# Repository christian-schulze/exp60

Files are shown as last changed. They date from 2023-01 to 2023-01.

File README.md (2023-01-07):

# Exp60 - An opinionated 60% with arrow keys PCB

---

> **Warning** WIP - Functioning prototype not built yet.
>
> - Components ordered (2023-01-06).
> - PCB's ordered (2023-01-07).

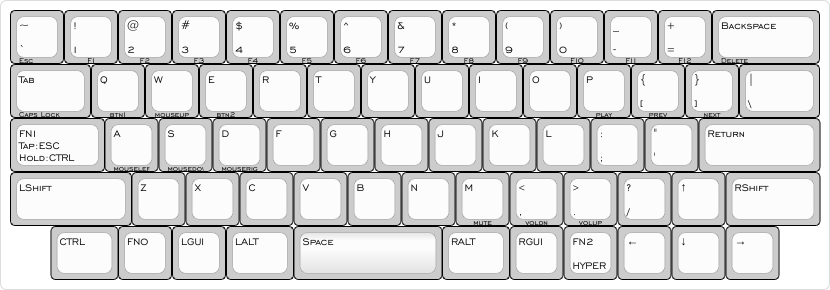
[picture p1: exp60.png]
Exp60 Layout


[Link to Keyboard Layout Editor project](http://www.keyboard-layout-editor.com/#/gists/84f70adc6e3be321baacc794c3d78efd)

## Why?

I've always preferred the size of a 60%, but never managed to kick the arrow key addiction. Having tried the `dz60` and `dz64` from kbdfans (dz64 being my fav), they both have trade-offs I've never been quite happy with.

## Design constraints

1. 60% form factor, roughly the same size as a GH60.
2. Arrow cluster
3. Standard 2.25U left shift
4. Standard 1U forward slash / question mark key
5. Bottom row should have `CTRL`, `Fn`, `GUI`, `ALT` and `HYPER` keys
6. USB-C
7. Hot-swap
8. Hand solderable

## How was this layout chosen?

In order to meet design constraints 2, 3 and 4, the arrow cluster needs to be located next to the forward slash key. The right arrow key only has 0.75U of space to its right, so we have the `HHKB-esque` gaps at the edges of the bottom row.

To meet design constraint 5, the space bar needs to be shrunk to 2.75U. I've been daily driving a heavily modded `HHKB Pro JP` since 2017 so this is A-OK to me.

## PCB Design choices

1. All SMD components due to limited space.
2. Use `atmega32u2-au` MCU instead of `atmega32u4-au` due to limited space (32 vs 48 pins).
3. Large footprint SMD components so everything is more easily hand solderable.

## Acknowledgements

- [JP60 by ai03](https://github.com/ai03-2725/JP60)

  60%, USB-C, ESD and over voltage/currrent protection.

- [Keyboard Matías](https://github.com/nstrappazzonc/keyboard)

  This uses the `atmega32u2-au`, which is crucial for fitting the MCU and related traces on my PCB.

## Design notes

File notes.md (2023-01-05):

switch gap:
5.050

switch width:
14

stab width:
7.250

------------------------------------------------

switch radius:
9.525

x1: 80.455 - 9.525 = 70.930
y1: 93.155 - 9.525 = 83.630

x2: 340.01125 + 16.669 = 356.68025
y2: 169.355 + 9.525 = 178.880

w: 356.68025 - 70.930 = 285.75025
h: 178.880 - 83.630 = 95.25

diode position from center of switch:
x: 7.65125
y: 1.500

parallel diode gap:
2.95

parallel horizontal diode:
x: 5.04875
y: 3.145
gap: 2.95

column via gaps:
X: 78.1325 - 76.2 = 1.9325
Y: 99.21875 - 98.235 = 0.98375

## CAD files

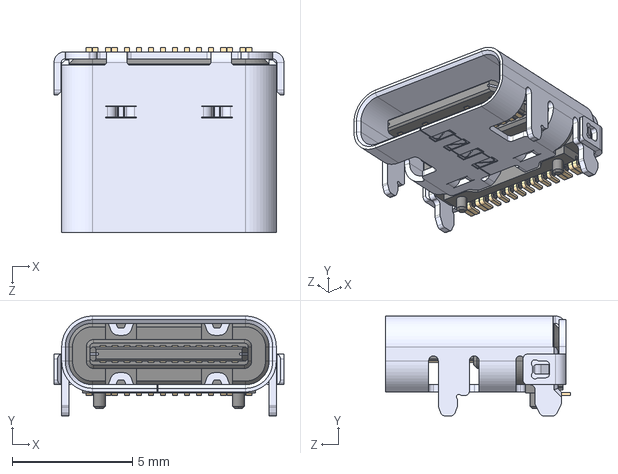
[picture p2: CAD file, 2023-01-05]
kicad/USB4105-GF-A/USB4105-GF-A.step
9.58 x 4.16 x 7.71 mm

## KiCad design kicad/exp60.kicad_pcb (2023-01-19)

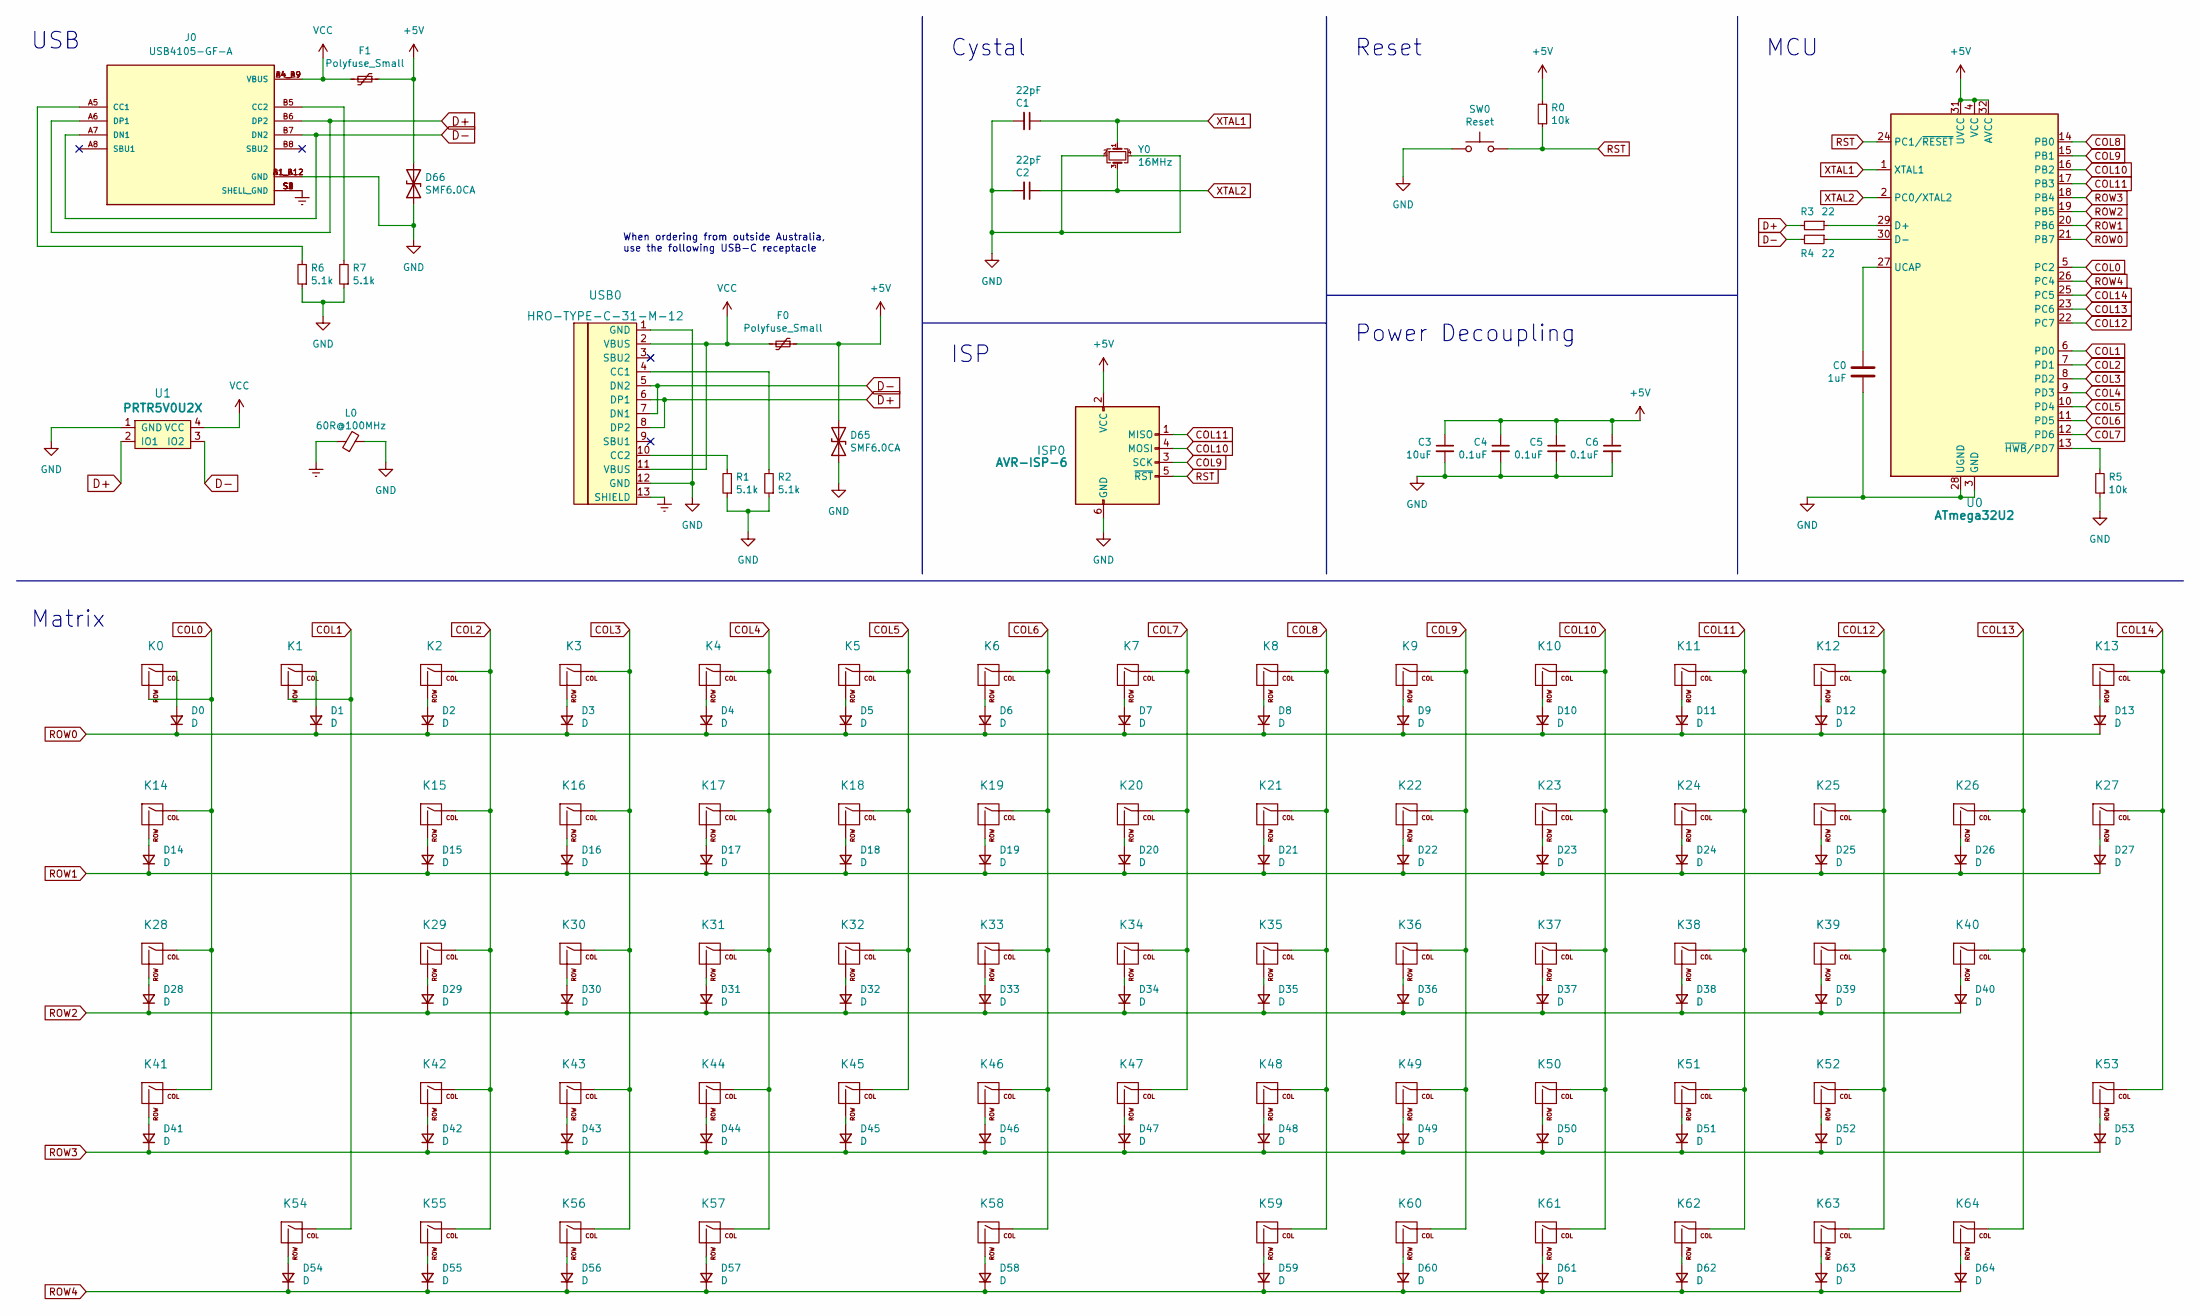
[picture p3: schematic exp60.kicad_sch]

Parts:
C0: 1uF; C_0805_2012Metric
C1, C2: 22pF; C_0805_2012Metric
C3: 10uF; C_0805_2012Metric
C4, C5, C6: 0.1uF; C_0805_2012Metric
D0, D1, D2, D3, D4, D5, D6, D7, D8, D9, D10, D11, D12, D13, D14, D15, D16, D17, D18, D19, D20, D21, D22, D23, D24, D25, D26, D27, D28, D29, D30, D31, D32, D33, D34, D35, D36, D37, D38, D39, D40, D41, D42, D43, D44, D45, D46, D47, D48, D49, D50, D51, D52, D53, D54, D55, D56, D57, D58, D59, D60, D61, D62, D63, D64: D; D_SOD-123
D65, D66: SMF6.0CA; D_SOD-123
F0, F1: Polyfuse_Small; Fuse_1206_3216Metric
ISP0: AVR-ISP-6; CON_TC2030_outlined
J0: USB4105-GF-A; GCT_USB4105-GF-A-HandSoldering; PARTREV A3
K0, K1, K2, K3, K4, K5, K6, K7, K8, K9, K10, K11, K12, K15, K16, K17, K18, K19, K20, K21, K22, K23, K24, K25, K26, K29, K30, K31, K32, K33, K34, K35, K36, K37, K38, K39, K42, K43, K44, K45, K46, K47, K48, K49, K50, K51, K52, K55, K56, K60, K61, K62, K63, K64: KEYSW; MXOnly-1U-Hotswap
K13: KEYSW; MXOnly-2U-Hotswap
K14, K27: KEYSW; MXOnly-1.5U-Hotswap
K28, K53: KEYSW; MXOnly-1.75U-Hotswap
K40, K41: KEYSW; MXOnly-2.25U-Hotswap
K54, K57, K59: KEYSW; MXOnly-1.25U-Hotswap
K58: KEYSW; MXOnly-2.75U-Hotswap-ReversedStabilizers
L0: 60R@100MHz; L_1206_3216Metric
R0, R5: 10k; R_0805_2012Metric
R1, R2, R6, R7: 5.1k; R_0805_2012Metric
R3, R4: 22; R_0805_2012Metric
SW0: Reset; SW_SPST_SKQG_WithStem
U0: ATmega32U2; TQFP-32_7x7mm_P0.8mm
U1: PRTR5V0U2X; SOT-143_Handsoldering
USB0: HRO-TYPE-C-31-M-12; HRO-TYPE-C-31-M-12-HandSoldering
Y0: 16MHz; Crystal_SMD_3225-4Pin_3.2x2.5mm_HandSoldering

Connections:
+5V: C3.1, C4.1, C5.1, C6.1, D65.2 (A2), D66.2 (A2), F0.1, F1.1, ISP0.2 (VCC), R0.2, U0.4 (VCC), U0.31 (UVCC), U0.32 (AVCC)
COL0: K0.2 (ROW), K14.1 (COL), K28.1 (COL), K41.1 (COL), U0.5 (PC2)
COL1: K1.2 (ROW), K54.1 (COL), U0.6 (PD0)
COL2: K2.1 (COL), K15.1 (COL), K29.1 (COL), K42.1 (COL), K55.1 (COL), U0.7 (PD1)
COL3: K3.1 (COL), K16.1 (COL), K30.1 (COL), K43.1 (COL), K56.1 (COL), U0.8 (PD2)
COL4: K4.1 (COL), K17.1 (COL), K31.1 (COL), K44.1 (COL), K57.1 (COL), U0.9 (PD3)
COL5: K5.1 (COL), K18.1 (COL), K32.1 (COL), K45.1 (COL), U0.10 (PD4)
COL6: K6.1 (COL), K19.1 (COL), K33.1 (COL), K46.1 (COL), K58.1 (COL), U0.11 (PD5)
COL7: K7.1 (COL), K20.1 (COL), K34.1 (COL), K47.1 (COL), U0.12 (PD6)
COL8: K8.1 (COL), K21.1 (COL), K35.1 (COL), K48.1 (COL), K59.1 (COL), U0.14 (PB0)
COL9: ISP0.3 (SCK), K9.1 (COL), K22.1 (COL), K36.1 (COL), K49.1 (COL), K60.1 (COL), U0.15 (PB1)
COL10: ISP0.4 (MOSI), K10.1 (COL), K23.1 (COL), K37.1 (COL), K50.1 (COL), K61.1 (COL), U0.16 (PB2)
COL11: ISP0.1 (MISO), K11.1 (COL), K24.1 (COL), K38.1 (COL), K51.1 (COL), K62.1 (COL), U0.17 (PB3)
COL12: K12.1 (COL), K25.1 (COL), K39.1 (COL), K52.1 (COL), K63.1 (COL), U0.22 (PC7)
COL13: K26.1 (COL), K40.1 (COL), K64.1 (COL), U0.23 (PC6)
COL14: K13.1 (COL), K27.1 (COL), K53.1 (COL), U0.25 (PC5)
D+: J0.A6 (DP1), J0.B6 (DP2), R3.2, U1.2 (IO1), USB0.6 (DP1), USB0.8 (DP2)
D-: J0.A7 (DN1), J0.B7 (DN2), R4.2, U1.3 (IO2), USB0.5 (DN2), USB0.7 (DN1)
Earth: J0.S1 (SHELL_GND), J0.S2 (SHELL_GND), J0.S3 (SHELL_GND), J0.S4 (SHELL_GND), L0.1, USB0.13 (SHIELD)
GND: C0.2, C1.2, C2.2, C3.2, C4.2, C5.2, C6.2, D65.1 (A1), D66.1 (A1), ISP0.6 (GND), J0.A1_B12 (GND), J0.B1_A12 (GND), L0.2, R1.1, R2.1, R5.1, R6.1, R7.1, SW0.2, U0.3 (GND), U0.28 (UGND), U1.1 (GND), USB0.1 (GND), USB0.12 (GND), Y0.2, Y0.4
unnamed: C0.1, U0.27 (UCAP)
unnamed: D0.2 (A), K0.1 (COL)
unnamed: D1.2 (A), K1.1 (COL)
unnamed: D2.2 (A), K2.2 (ROW)
unnamed: D3.2 (A), K3.2 (ROW)
unnamed: D4.2 (A), K4.2 (ROW)
unnamed: D5.2 (A), K5.2 (ROW)
unnamed: D6.2 (A), K6.2 (ROW)
unnamed: D7.2 (A), K7.2 (ROW)
unnamed: D8.2 (A), K8.2 (ROW)
unnamed: D9.2 (A), K9.2 (ROW)
unnamed: D10.2 (A), K10.2 (ROW)
unnamed: D11.2 (A), K11.2 (ROW)
unnamed: D12.2 (A), K12.2 (ROW)
unnamed: D13.2 (A), K13.2 (ROW)
unnamed: D14.2 (A), K14.2 (ROW)
unnamed: D15.2 (A), K15.2 (ROW)
unnamed: D16.2 (A), K16.2 (ROW)
unnamed: D17.2 (A), K17.2 (ROW)
unnamed: D18.2 (A), K18.2 (ROW)
unnamed: D19.2 (A), K19.2 (ROW)
unnamed: D20.2 (A), K20.2 (ROW)
unnamed: D21.2 (A), K21.2 (ROW)
unnamed: D22.2 (A), K22.2 (ROW)
unnamed: D23.2 (A), K23.2 (ROW)
unnamed: D24.2 (A), K24.2 (ROW)
unnamed: D25.2 (A), K25.2 (ROW)
unnamed: D26.2 (A), K26.2 (ROW)
unnamed: D27.2 (A), K27.2 (ROW)
unnamed: D28.2 (A), K28.2 (ROW)
unnamed: D29.2 (A), K29.2 (ROW)
unnamed: D30.2 (A), K30.2 (ROW)
unnamed: D31.2 (A), K31.2 (ROW)
unnamed: D32.2 (A), K32.2 (ROW)
unnamed: D33.2 (A), K33.2 (ROW)
unnamed: D34.2 (A), K34.2 (ROW)
unnamed: D35.2 (A), K35.2 (ROW)
unnamed: D36.2 (A), K36.2 (ROW)
unnamed: D37.2 (A), K37.2 (ROW)
unnamed: D38.2 (A), K38.2 (ROW)
unnamed: D39.2 (A), K39.2 (ROW)
unnamed: D40.2 (A), K40.2 (ROW)
unnamed: D41.2 (A), K41.2 (ROW)
unnamed: D42.2 (A), K42.2 (ROW)
unnamed: D43.2 (A), K43.2 (ROW)
unnamed: D44.2 (A), K44.2 (ROW)
unnamed: D45.2 (A), K45.2 (ROW)
unnamed: D46.2 (A), K46.2 (ROW)
unnamed: D47.2 (A), K47.2 (ROW)
unnamed: D48.2 (A), K48.2 (ROW)
unnamed: D49.2 (A), K49.2 (ROW)
unnamed: D50.2 (A), K50.2 (ROW)
unnamed: D51.2 (A), K51.2 (ROW)
unnamed: D52.2 (A), K52.2 (ROW)
unnamed: D53.2 (A), K53.2 (ROW)
unnamed: D54.2 (A), K54.2 (ROW)
unnamed: D55.2 (A), K55.2 (ROW)
unnamed: D56.2 (A), K56.2 (ROW)
unnamed: D57.2 (A), K57.2 (ROW)
unnamed: D58.2 (A), K58.2 (ROW)
unnamed: D59.2 (A), K59.2 (ROW)
unnamed: D60.2 (A), K60.2 (ROW)
unnamed: D61.2 (A), K61.2 (ROW)
unnamed: D62.2 (A), K62.2 (ROW)
unnamed: D63.2 (A), K63.2 (ROW)
unnamed: D64.2 (A), K64.2 (ROW)
unnamed: J0.A5 (CC1), R6.2
unnamed: J0.B5 (CC2), R7.2
unnamed: R1.2, USB0.10 (CC2)
unnamed: R2.2, USB0.4 (CC1)
unnamed: R3.1, U0.29 (D+)
unnamed: R4.1, U0.30 (D-)
unnamed: R5.2, U0.13 (~HWB/PD7)
ROW0: D0.1 (K), D1.1 (K), D2.1 (K), D3.1 (K), D4.1 (K), D5.1 (K), D6.1 (K), D7.1 (K), D8.1 (K), D9.1 (K), D10.1 (K), D11.1 (K), D12.1 (K), D13.1 (K), U0.21 (PB7)
ROW1: D14.1 (K), D15.1 (K), D16.1 (K), D17.1 (K), D18.1 (K), D19.1 (K), D20.1 (K), D21.1 (K), D22.1 (K), D23.1 (K), D24.1 (K), D25.1 (K), D26.1 (K), D27.1 (K), U0.20 (PB6)
ROW2: D28.1 (K), D29.1 (K), D30.1 (K), D31.1 (K), D32.1 (K), D33.1 (K), D34.1 (K), D35.1 (K), D36.1 (K), D37.1 (K), D38.1 (K), D39.1 (K), D40.1 (K), U0.19 (PB5)
ROW3: D41.1 (K), D42.1 (K), D43.1 (K), D44.1 (K), D45.1 (K), D46.1 (K), D47.1 (K), D48.1 (K), D49.1 (K), D50.1 (K), D51.1 (K), D52.1 (K), D53.1 (K), U0.18 (PB4)
ROW4: D54.1 (K), D55.1 (K), D56.1 (K), D57.1 (K), D58.1 (K), D59.1 (K), D60.1 (K), D61.1 (K), D62.1 (K), D63.1 (K), D64.1 (K), U0.26 (PC4)
RST: ISP0.5 (~RST), R0.1, SW0.1, U0.24 (PC1/~RESET)
VCC: F0.2, F1.2, J0.A4_B9 (VBUS), J0.B4_A9 (VBUS), U1.4 (VCC), USB0.2 (VBUS), USB0.11 (VBUS)
XTAL1: C1.1, U0.1 (XTAL1), Y0.1
XTAL2: C2.1, U0.2 (PC0/XTAL2), Y0.3

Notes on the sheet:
USB
Power Decoupling
Cystal
Matrix
When ordering from outside Australia, use the following USB-C receptacle
ISP
Reset
MCU

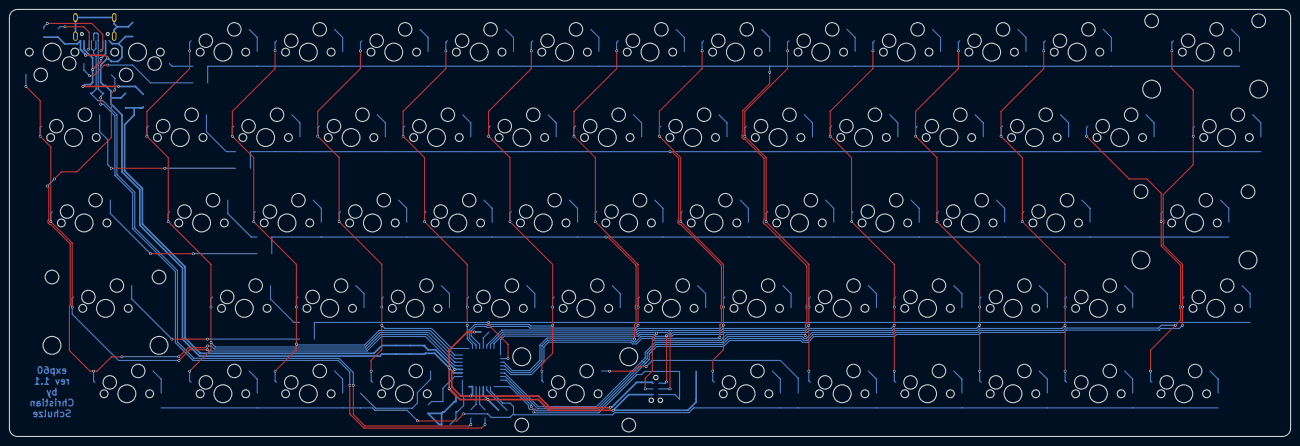
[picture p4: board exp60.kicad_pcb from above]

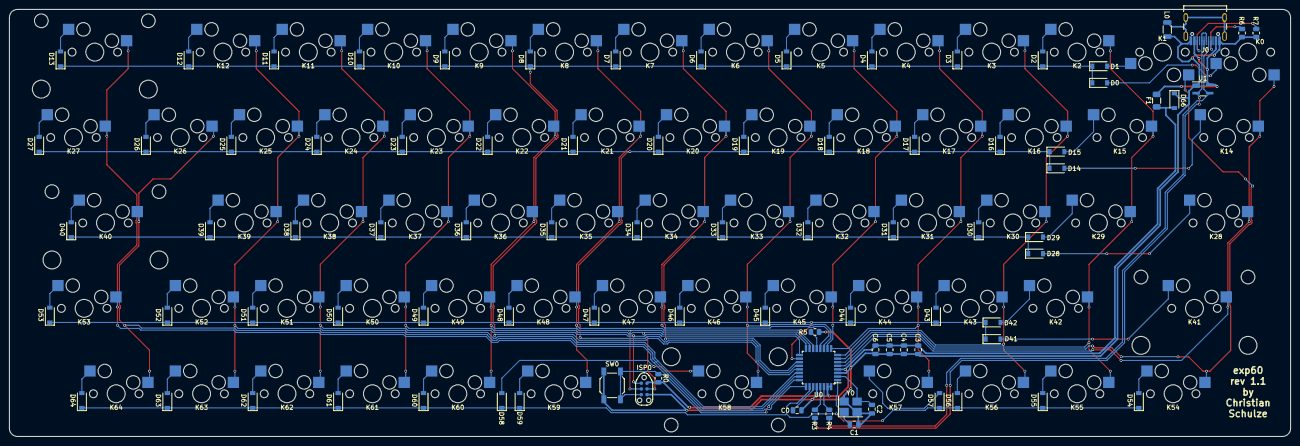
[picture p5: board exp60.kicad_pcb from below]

Board: 2 copper layers, 285.8 x 95.2 mm, 152 parts (87 on the bottom side), 100 nets.

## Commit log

2023-01-05 replace usb receptacle
    [USB4105-GF-A.step, exp60.kicad_pcb, exp60.kicad_sch]
2023-01-05 label and route cleanup
    [exp60.kicad_pcb]
2023-01-07 generate gerbers for prototype
    [exp60-B_Cu.gbr, exp60-B_Mask.gbr, exp60-B_Paste.gbr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]
2023-01-19 fix ISP pins, curved corners, larger component spacing
    [exp60-B_Cu.gbr, exp60-B_Mask.gbr, exp60-B_Paste.gbr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]
